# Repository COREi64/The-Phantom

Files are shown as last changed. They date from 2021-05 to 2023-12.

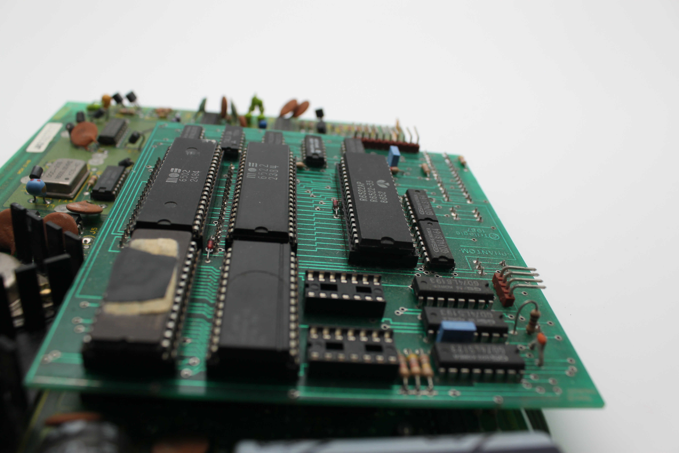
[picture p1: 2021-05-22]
Photos/Pre-Deconstruction Photos/1671.2021_04_24.JPG

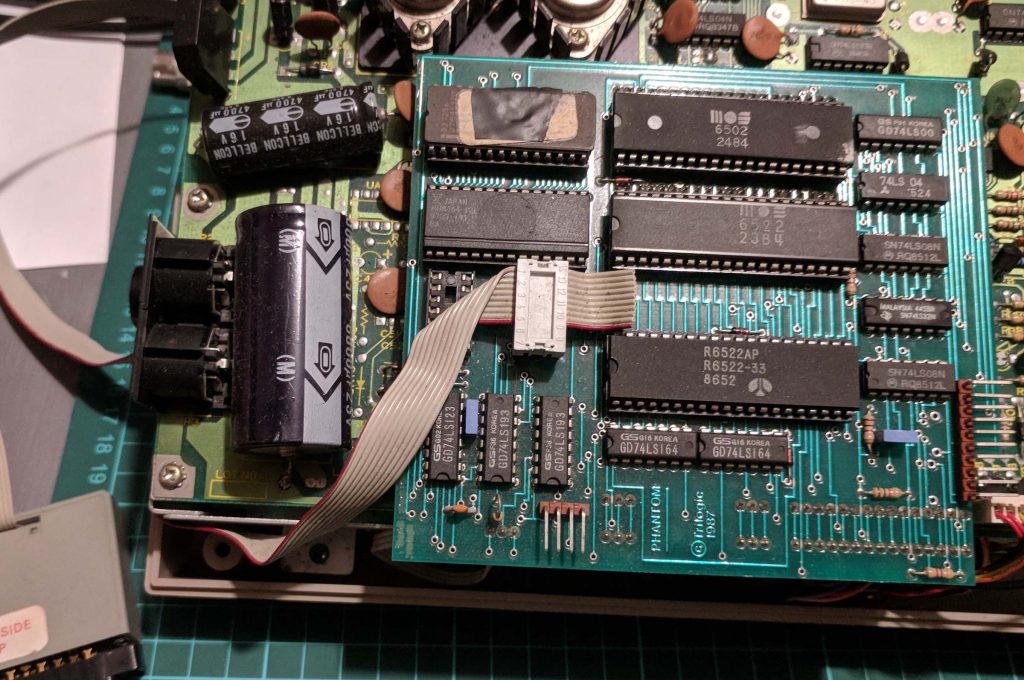
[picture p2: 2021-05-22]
Photos/Original Installation Photos/Phantom-Board-2-1024x680.jpg

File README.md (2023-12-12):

# The Phantom
Reproduction of the Phantom 1541 Drive Enhancement

Order your PCB's for this project directly from PCBWay, using the following links:

Back in about the 1986 timeframe, Tri-logic (UK) began marketing a board named "The Phantom".  I cannot speak to the commercial success of this product, today this board is one of the most rare Commodore "artifacts" known to still exist, especially in north america.  Being a product that resided within the host Commodore 64 and 1541 disk drive, it's reasonable to expect that as the years progressed knowledge that the product was installed in the system would have been forgotten.  Then, as the years march on, these machines are disposed of, given that those people have moved on with technology.

As a result, very few examples of this exist anymore.  For the most part, all that remained was a few short reviews, a magazine advertisement and miraculously a copy of the dedicated copier program that worked in concert with the board.  But up until recently the board has simply been gone.

A few years ago a good friend of mine (John Barrell) mentioned to me that he had found one of these installations in a Commodore job-lot that he had purchased local to him.  To understand who John was, is to think of a good natured man who shared a passion for Commodore products and was focused on the preservation of this hardware and software.  John however did not possess the skills to recreate the installation.  I offered to do this for him, as I had previously preserved other hardware such Chip Gracey's ISEPIC cartridge.  John and I came to an arrangement and he shipped the boards (drive board and kernal board) to me.  Unfortunately John passed away earlier this year, and never had the chance to see his wish come true.  Johns goal was the preservation of this hardware, and I am going to ensure that his wish is fulfilled.

This project has long since passed verification and testing, and has been found to be a fully functional, fully tested re-creation of the original Phantom drive accelerator.  This project in it's entirety is now available here in this github repository for anyone in the community to build and enjoy.  John wanted this product to the preserved for future entheusiasts.  This wish of his has now been realized.  Unfortunately we have not yet located the original documentation for the Phantom.  As such, all of the commands and features listed in the "user manual" is information that has been gleaned through testing, advertisements and disassembly.  Some of the features remain elusive.  I am hopeful that one day someone will locate an original Phantom manual and donate scans/photos of this document to this repository.

I will continue adding information as I work through this project and as more information becomes available.

If you fancy building this yourself, I've uploaded the board files to PCBWay's Shared Projects, so anyone can order their very own PCB's and build their own Phantom!  How exciting eh!  The Phantom is now within your reach.  Click on the links below to order the boards.

<a href="https://www.pcbway.com/project/shareproject/Tri_Logic_Phantom_Main_1541_Drive_Board_4dde7b70.html">PCB from PCBWay</a> <B>Click to order the Phantom Drive Board PCB</B>

<a href="https://www.pcbway.com/project/shareproject/Tri_Logic_Phantom_Kernal_Board_199d37ed.html">PCB from PCBWay</a><B>Click to order the Phantom Kernal Board PCB</B>

<a href="https://www.pcbway.com/project/shareproject/Tri_Logic_Phantom_Userport_Board_2852a004.html">PCB from PCBWay</a><B>Click to order the Phantom Userport Board PCB</B>

Phantom-AD-766x1024

NOTE: Effective March 5th, 2023, I have uploaded the design files as well as the gerbers of this project so that this wonderful product, that was almost lost to history, can be preserved and enjoyed well into the future.

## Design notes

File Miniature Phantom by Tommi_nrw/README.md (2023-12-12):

This is a variant of the original Phantom Reproduction found in this github that was supplied by John Barrel.

Based entirely on that work, this is an optimized reduced version of the original Trilogic Phantom.  The board is physically quite a bit smaller, and much easier to install as a result of this.
The design has been tested by the project creator and found to function correctly.  So for those looking to build a Phantom to experience what it was like, in a smaller easier to build package, this is certainly a version that could be considered.

Although there is no PCB at the moment for the parallel cable, I'm hoping that one will become available to make the deployment of this version easier, as it can be confusing as to how to wire the PCB without access to a convenient parallel cable PCB.

It should be noted that Thomas Linke has donated this project to this original Phantom Github repository for the Commodore community to enjoy for those that come after us.  The effort spent on creating this terrific board is greatly appreciated and is a wonderful addition to this continually expanding repository of all things Phantom related.

COREi64

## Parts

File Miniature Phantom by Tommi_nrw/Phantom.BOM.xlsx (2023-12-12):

IC1 | 6502 | 40 pin socket
IC2 | 6522 | 40 pin socket
IC3 | 6522 | 40 pin socket
IC4 | 6264 | 28 pin socket
IC5 | 28C256 | 28 pin socket
IC6 | 47LS123 | 16 pin socket
IC7 | 47LS08 | 14 pin socket
IC8 | 74LS193 | 16 pin socket
IC9 | 47LS00 | 14 pin socket
IC10 | 74LS164 | 14 pin socket
IC11 | 74LS04 | 14 pin socket
IC12 | 74LS32 | 14 pin socket
IC13 | 74LS164 | 14 pin socket
IC14 | 74LS08 | 14 pin socket
IC15 | 74LS193 | 16 pin socket
C1-15 | 100nF
C6A | 47pF
C6B | 100nF
CW | 100nF | (not needed)
R1 | 1k
R2 | 100k
R3-R6 | 4k7
JP1 | 2x7 pinheader | for parallelcable
PX | 1x5 pinheader | (not needed)
JP3 | 12x1 pinheader | on/off, Dev#...
P3 | 3x1 pinheader | connection to UC1
WP | 2x1 pinheader | for connecting writeprotection input/output

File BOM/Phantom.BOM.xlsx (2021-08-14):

Phantom Drive Board Bill of Materials
Part ID | Parts | Mouser Part number | QTY | Description |  | Source
 | 27256 |  | 1 | EPROM |  |  | Compatible SRAM
 | MB8464-12L |  | 1 | SRAM
 | 6502 |  | 1 | CPU/MOS |  | Obtained from 1541 Drive Board | Goldstar | 76C88
 | 6522 | 955-W65C22N6TPG-14 | 2 | Versatile Interface Adapter (VIA/MOS) |  | One obtained from 1541 Drive Board | Hitachi | 6264
 | 74LS123 | 595-SN74LS123N | 1 | dual retriggerable monostable multivibrator, clear |  |  | Hyundi | 6264
 | 74LS193 | 595-SN74LS193N | 2 | synchronous presettable up/down 4-bit binary counter, clear |  |  | Mitsubishi | 5165
 | 74LS164 | 595-SN74LS164N | 2 | 8-bit serial-in parallel-out (SIPO) shift register, asynchronous clear, not output latch |  |  | Mosel/Vitelic | 6264
 | 74LS00 | 595-SN74LS00N | 1 | quad 2-input NAND gate |  |  | NEC | 4464
 | 74LS04 | 595-SN74LS04N | 1 | hex inverter gate |  |  | OKI | 5165
 | 74LS08N | 595-SN74LS08N | 2 | quad 2-input AND gate |  |  | Samsung | 6264
 | 74LS32N | 595-SN74LS32N | 1 | quad 2-input OR gate |  |  | Sony | 5864B
 |  |  |  |  |  |  | Toshiba | 5564/5565
R1, R4, R5, R6, R8 | 1K | 660-MFS1/4CCT52R1001 | 5 | Resistor
R2, R7 | 4.7K | 660-MF1/4CCT52R4701F | 2 | Resistor
R3 | 100K | 660-MFS1/4DC1003F | 1 | Resistor
D1, D2, D3 | 1N4148 | 512-1N4148 | 3 | Fast switching diode
C2 | 47p ceramic | 810-FG28C0G1H470JNT0 | 1 | 47p Ceramic Capacitor
C1, C3 | Mkt-hq-370-ph | 80-RSBDC3100DQ00K | 2 | 100nf 10 63v Polyester Film Capacitor
 | 28p wide socket |  | 2 | double wipe
 | 40p wide socket |  | 5 | double wipe
 | 14p narrow socket |  | 9 | double wipe
 | 16p narrow socket |  | 3 | double wipe
 | 15p 2.54 female strip |  | 1 | straight
 | 3p 2.54 female strip |  | 2 | straight
 | 15p 2.54 male strip |  | 1 | straight
 | 3p 2.54 male strip |  | 3 | straight
 | ~~10p 2.54 male strip~~ |  | 0 | 90 degree | Not needed - these are test points used when the board was developed.
 | ~~4p 2.54 male strip~~ |  | 0 | 90 degree | Not needed - these are test points used when the board was developed.
 | 40p machine pin strip |  | 4 | straight
Phantom Kernal Board Bill of Materials
Part ID | Parts |  | QTY | Description |  | Source
 | 28p wide socket |  | 1 | double wipe
 | 24p machine pin strip, male/male |  | 2 | straight
 | 3p 2.54 male strip |  | 1 | 90 degree
 | 3p Dupont cable with 3p female |  | 1 | *for switch to toggle kernals
 | DPST switch |  | 1 | *for switch to toggle kernals
 | 2.2K |  | 2 | 0805 Resistor
 | 27256 |  | 1 | EPROM/EEPROM
 | PCB |  | 1 | Phantom Kernal PCB
Phantom Parallel Connector Board Bill of Materials
Part ID | Parts |  | QTY | Description |  | Source
 | 10 conductor ribbon cable |  | 4 ft
 | 7p machine pin strip, male/male |  | 4
 | Userport edge connector |  | 1
 | PCB |  | 1 | Phantom Parallel Connector PCB
 | 3D Designed Userport Connector Case |  | 1

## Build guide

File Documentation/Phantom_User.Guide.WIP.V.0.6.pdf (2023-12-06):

The PHANTOM

INSTRUCTIONS
Version 0.6

PLEASE READ THIS
BOOKLET BEFORE
USING THE PHANTOM

## The Phantom

### INTRODUCTION:

Thank-you for buying (or building your very own) the NEW! Phantom. The parallel disk turbo system every 1541 wants but nobody’s been able to get since 1987!

- Expert Compatible – Program the Expert in less than 2 seconds
- Speeds up ALL drive functions
- Full error checking retained – essential for
reliability. | Other | systems | sacrifice | this
crucial function to achieve speed increases but are in fact NO FASTER, only LESS RELIABLE.
- 8 function key commands for major functions.
- 60 additional commands including
- File lock and unlock
- Write protect ignore, no need to notch disks
- Set device number
- Screen on/off
- GO1541 – reverts to standard 1541
- Many | more | useful | commands | aid
compatibility | (disable | function | keys,
disable extra ram etc.)
- Drive | monitor | – | commands | include
disassemble, | fill, | compare, | hunt,
assemble, execute etc etc.
- Compatible with most commercial software.
- Reliable – does not corrupt disks unlike rival products.
- Switchable kernel replacement included for 64 or 128 (in 64 mode)
- British designed and manufactured, available exclusively from Trilogic
- Upgradable – DOS, Kernal & Copier upgrades will be available soon to give extra features for a nominal sum.

- The LOAD command can load files under the I/O area, so theoretically you can load 248 blocks (from the start of basic at $0801) or even 252 block files (starting from the tape buffer). This has never been seen in any other speeder ever created for the Commodore.

The Phantom consists of these components.

1. Phantom Drive Board
2. Phantom Drive Board Sync Cable
3. Phantom Kernal Replacement with Switch
4. Parallel Cable

Please read/reference the installation section of this manual for correct installation of your new Phantom. Trilogic cannot be held responsible for any damage caused due to incorrect installation.

### Compatibility:

The Trilogic Phantom board is compatible with all “long board” Commodore 1541 disk drives (110v & 220v
models). | These are the drives manufactured around
1987 or prior. | You can tell the drive is correct as
it will look like the following picture.

<<< INSERT PHOTO HERE >>>

In terms of Commodore 64 compatibility, so long as the computer has a socketed kernal ROM, it can be deemed compatible. If your computer doesn’t have a socketed kernal ROM, then you’re going to have to remove the ROM and replace it with a socket.

If this is beyond your capability, seek competent professional assistance.

### Keyboard Shortcuts:

The following are various keyboard shortcuts incorporated into the Phantom hardware to assist in making your computing experience more productive.

<CTRL-RESTORE>:

Resets the screen colors to the original factory default state of dark blue screen, light blue border and light blue text. Does not affect the contents of memory.

<RUNSTOP-RESTORE>:

Resets the screen colors to the PHANTOM default state of dark grey screen, light grey border and yellow text. Does not affect the contents of memory.

<RUNSTOP-( key)>:

Resets the computer as though you pressed a hardware reset button or issued an SYS64738 reset command.

<CommodoreKey-RUNSTOP>:

Loads the first file on your diskette into basic memory space. The command that’s issued is LOAD”0:*”,8

<SHIFT-RUNSTOP>:

Loads the first file on your diskette into the memory space where the program was originally saved from. The command that’s issued is LOAD”0:*”,8,1

Function Keys:

f1 - @8$:*
f2 - @9$:*

f3 - LOAD
f4 - SAVE"
f5 - RUN:
f6 - LIST
f7 - @
f8 - sys61916

### Built-In Functions:

Custom Directory Function: £

This feature allows you to create a customized directory of your diskette. To further explain I will illustrate with an example.

As we all know, it’s possible to have a LOT of different programs on a single side of a diskette given it’s large capacity of 170KB of storage space. And each of these programs can be made up of many different files. As such, it can be difficult to quickly determine what exactly is on the disk. Well, the Phantom to the rescue.

Let’s assume that you have the following programs on your disk.

1 Jumpman
2 Gyruss
3 Ms.Pacman
4 Ft. Apocalypse
5 Dig Dug
6 Drol
7 BCs Quest for Tires
So, that’s a lot of files. | To make a custom
directory, you’ve just seen the first step. | Enter
your list of programs that you’d find on your disk as shown above. It looks like a little program with line numbers right? Good.

Now with your diskette in the drive, and the write protect open, type the following:

SAVE “£”,8 (assuming your drive is 8)

That’s it.

Now to use the custom directory, type the following:

$£

Instead of displaying the actual directory, it will show you that list you just created. And the beauty of it is that you can put anything in that list you want to make it as meaningful as you’d like!

Interactive Editor Function:

Very little at this point is known about this function. I will highlight what is currently known, and update as more information becomes available.

@U0S<FILENAME>

This command opens the “FILENAME” for write output, and creates that file as a PRG file on the floppy disk. When this command is issued, the drive starts spinning, and the FILENAME <prg extension> is created on the diskette and opened for writing.

@U0L<FILENAME>

This command is presumably to load the above noted “FILENAME” and display it on the screen.

*** more testing and investigation is required for this command.

### Commands:

@ : Command Character:

This is the character that prefixes all DOS commands. It is interchangeable with the > command.

> : Command Character:

This is the character that prefixes all DOS commands. It is interchangeable with the @ command.

@& : Utility Loader:

The utility loader is the command which will load a USR file from disk into disk drive memory where it will then execute. The filename must be of a USR type, and the filename must be prefixed with the & character.

It should further be noted that when using this command, the <filename> you enter in the syntax below must have the & omitted.

Syntax/variants:

@&<filename>

The syntax assumes you have a file on floppy disk of a USR format, prefixed with the & character.

@£ : <<< unknown >>>:

This command generates 62, file not found, 00, 00 error.

Syntax/variants:

Have yet to determine the syntax for this.

@= : System Status:

This command displays a list of current option status’ as well as the drive rom identification. This may also do a soft reset on the drive at the same time (unconfirmed)

Syntax/variants:

Displays the following information.

73,8K PHANTOM DOS V1.1E,08,08
90, RAM ENABLED,00,00
91,TURBO ENABLED,00,00
92,SCREEN BLANKING ENABLED,00,00 98,BUMPS ENABLED,00,00
99,WRITE PROTECT ENABLED,00,00

@$ : Directory:

This command will display the contents of the directory on the diskette. The <Commodore-key> will pause the directory listing, and the RUNSTOP key will stop the directory listing. These are ideally suited for when you’re looking at a very long directory or you want to stop part way through when you’ve found what you’ve been looking for.

Syntax/variants:

@$ (directory of drive 0 of current device) @$$ (shows directory header & blocks free only) @0:$ (directory of drive 0 of current device) @0:$pa (only shows files starting with “pa”)

@1 : Enable TAPE Support:

I’m listing this separately to bring it to your attention that this is how you enable TAPE support. Normally, when powered up, TAPE support is not available, as the default commands are focused directly to the disk drive. By issuing this command you are redirecting focus to the TAPE drive. All subsequent I/O commands that would normally be directed to the drive now go to TAPE.

Syntax:

@1

Functional Example:

Once the command is issued, LOAD or SAVE will access the plugged in datasette recorder.

@n : Directing DOS commands to a specific Drive number:

In order to “focus” your machine on a specific drive number, you can issue the @<number> command. This will direct focus of all future DOS commands for your computing session or until you change it to a specific drive number.

Syntax:

@<drive number>

Functional Example:

@8 – Will direct all DOS commands to drive 8 @9 – Will direct all DOS commands to drive 9 @10 – Will direct all DOS commands to drive 10

@An : Soft Re-Numbering your Drive:

The disk drive, by default from the factory, is device #8. Unless you’ve physically changed this on the 1541 logic board, your drive will have that drive number assigned to it when you power it on. Soft renumbering allows you to change the device number of your drive without any physical changes.

Syntax:

@A <device-number>

Functional Example:

In order to use this command, DOS must have focus
on your current active drive. | By default, we
will assume that your drive is device 8. | To
ensure DOS focus on drive 8, you can issue the @8 command. After that you can change the device to another number.

@A9 will then soft renumber your 1541 to device 9.

To change it back, or to issue any DOS commands on the newly renumbered drive, you need to first issue an @9 to direct your DOS focus to that drive.

Then, you can issue any DOS command and it will be directed by your computer to device 9.

To change it back, or to any other device number, simply issue the @A8 command to change your drives number back to device 8. Don’t forget to re-focus DOS to device 8 now using the @8 command.

@BH : Seek Drive Head to Track Zero:

The purpose of this is to force the drive to find track 0 on your floppy drive. There are times when your floppy drive head may become “lost”, that could prevent you from loading a directory or any software for that matter. Issuing an @BH will correct that problem.

Syntax:

@BH

Functional Example:

@BH <return>

From the basic prompt, type @BH and press return. The drive will spin, and you will hear a slight banging in your drive. This is a normal sound. Once the drive stops spinning, the process is complete.

@BQ : <<<unknown>>>:

The purpose of this command is unknown.

Syntax / Functional Example:

This command issued as @BQ will generate a machine response of:

10, no track 1 sensor, 00, 00

@CD : <<<unknown>>>:

The purpose of this command is unknown.

Syntax / Functional Example:

This command issued as @BQ will generate a machine response of:

26, write protect on, 18, 01

@EA : Enable ALL:

The purpose of this command is to enable all of the listed system functions. Regardless of what their current state is, this command will enable them all and display their status on the screen.

Syntax :

@EA

Functional Example:

Enables all functions and returns a response on the screen as the example shows:

@EA <return>

90,RAM ENABLED, 00, 00
91,TURBO ENABLED, 00, 00
92,SCREEN BLANKING ENABLED, 00, 00 93,PHANTOM COMMANDS ENABLED, 00, 00 94,FAST SAVER ENABLED, 00, 00 95,FAST FORMAT ENABLED, 00, 00
96,PARALLEL BUS ENABLED, 00, 00
98,BUMPS ENABLED, 00, 00

It should also be noted that the @EA command can be stacked with other single commands that follow: Examples are as follows:

@EBC <return> will enable Bumps and Phantom Commands the following

98,BUMPS ENABLED, 00, 00
93,PHANTOM COMMANDS ENABLED, 00, 00

@ENP <return> will enable Fast Save and Parallel Bus with the following

94,FAST SAVER ENABLED, 00, 00
96,PARALLEL BUS ENABLED, 00, 00

EB : Enable Bumps:

The purpose of this command is to activate the “Bumps Enabled” to the current state.

Syntax :

@EB

Functional Example:

Returns a response on the screen as the example shows:

@EB <return>

98,BUMPS ENABLED, 00, 00

@EC : Enable Phantom Commands:

The purpose of this command is to set the “Phantom Commands” as enabled to be the current state.

Syntax :

@EC

Functional Example:

Returns a response on the screen as the example shows:

@EC <return>

93,PHANTOM COMMANDS ENABLED, 00, 00

@EF : Enable Fast Saver:

The purpose of this command is to set the “Fast Saver” as enabled to be the current state.

Syntax :

@EF

Functional Example:

Returns a response on the screen as the example shows:

@EF <return>

94,FAST SAVER ENABLED, 00, 00

@EN : Enable Fast Format:

The purpose of this command is to set the “Fast Format” as enabled to be the current state.

Syntax :

@EN

Functional Example:

Returns a response on the screen as the example shows:

@EN <return>

95,FAST FORMAT ENABLED, 00, 00

@EP : Enable Parallel Bus:

The purpose of this command is to set the “Parallel Bus” as enabled to be the current state.

Syntax :

@EP

Functional Example:

Returns a response on the screen as the example shows:

@EP <return>

96,PARALLEL BUS ENABLED, 00, 00

@ER : Enable RAM:

The purpose of this command is to set the “RAM” as enabled to be the current state.

Syntax :

@ER

Functional Example:

Returns a response on the screen as the example shows:

@ER <return>

90,RAM ENABLED, 00, 00

@ES : Enable Screen Blanking:

The purpose of this command is to set the “Screen Blanking” as enabled to be the current state.

Syntax :

@ES

Functional Example:

Returns a response on the screen as the example shows:

@ES <return>

92,SCREEN BLANKING ENABLED, 00, 00

@ET : Enable Turbo:

The purpose of this command is to set the “Turbo” as enabled to be the current state.

Syntax :

@ET
@+
@-

Functional Example:

Returns a response on the screen as the example shows:

@ET <return>

91,TURBO ENABLED, 00, 00

To toggle Turbo mode, perform the following commands

@+ enables Turbo mode
@- disables Turbo mode

@FL : File Lock:

The purpose of this command is to lock one or
more files on diskette. | This prevents deletion
(scratching) of the file. | The only way to wipe
out a locked file is to unlock it first, or format the diskette.

File locking can be done to a single file, multiple specified files up to a maximum of 5 at once, or with a wildcard (*). Using a wildcard will allow you to do all of the files on a diskette.

When doing a list of up to five filenames, you cannot allow them to wrap to the next line, as this command does not support wrapping.

Syntax :

@FL:<file1>,<file2>,<file3>,<file4>,<file5> @FL:<filename>
@FL:*
@FL:F* (lock all files starting with F)

@FU : File UnLock:

The purpose of this command is to unlock one or more files on diskette. This allows deletion (scratching) of the file to be done if the user wishes to do so.

File unlocking can be done to a single file, multiple specified files up to a maximum of 5 at once, or with a wildcard (*). Using a wildcard will allow you to do all of the files on a diskette.

When doing a list of up to five filenames, you cannot allow them to wrap to the next line, as this command does not support wrapping.

Syntax :

@FU:<file1>,<file2>,<file3>,<file4>,<file5> @FU:<filename>
@FU:*
@FU:F* (unlock all files starting with F)

@GO1541 : Revert to Stock ROM:

The purpose of this command is to allow the user to revert the drive back to the original factory Commodore 1541 Drive ROM.

Syntax :

GO1541

Functional Example:

Returns a response on the screen as the example shows:

@GO1541 <return>

73,CBM DOS V2.6 1541,00,00

@H : Header:

The purpose of this command is to rename the header (diskette name) of the diskette. This is the name that is used when formatting a diskette, and the name that appears reversed when listing a directory.

This is a non-destructive process with respect to the data on the diskette. You may perform this function without risk of loss of data.

Syntax :

@H0:<header name>

Functional Example:

@H0:Trilogic Phantom

Take note that the header name you choose must be at least 1 character long and no longer than 16 characters.

@I : Initialize:

The purpose of this command is to initialize the diskette.

Syntax :

@I0:

@KA : Disable ALL:

The purpose of this command is to disable all of the listed system functions. Regardless of what their current state is, this command will disable them all and display their status on the screen.

Syntax :

@KA

Functional Example:

Enables all functions and returns a response on the screen as the example shows:

@KA <return>

90,RAM DISABLED, 00, 00
91,TURBO DISABLED, 00, 00
92,SCREEN BLANKING DISABLED, 00, 00 93,PHANTOM COMMANDS DISABLED, 00, 00 94,FAST SAVER DISABLED, 00, 00 95,FAST FORMAT DISABLED, 00, 00
96,PARALLEL BUS DISABLED, 00, 00
98,BUMPS DISABLED, 00, 00

It should also be noted that the @KA command can be stacked with other single commands that follow: Examples are as follows:

@KBC <return> will disable Bumps and Phantom Commands the following

98,BUMPS DISABLED, 00, 00
93,PHANTOM COMMANDS DISABLED, 00, 00

@KNP <return> will disable Fast Save and Parallel Bus with the following

94,FAST SAVER DISABLED, 00, 00
96,PARALLEL BUS DISABLED, 00, 00

@KB : Disable Bumps:

The purpose of this command is to de-activate the “Bumps Enabled” to the current state.

Syntax :

@KB

Functional Example:

Returns a response on the screen as the example shows:

@KB <return>

98,BUMPS DISABLED, 00, 00

@KC : Disable Phantom Commands:

The purpose of this command is to set the “Phantom Commands” as disabled to be the current state.

Syntax :

@KC

Functional Example:

Returns a response on the screen as the example shows:

@KC <return>

93,PHANTOM COMMANDS DISABLED, 00, 00

@KF : Disable Fast Saver:

The purpose of this command is to set the “Fast Saver” as disabled to be the current state.

Syntax :

@KF

Functional Example:

Returns a response on the screen as the example shows:

@KF <return>

94,FAST SAVER DISABLED, 00, 00

@KN : Disable Fast Format:

The purpose of this command is to set the “Fast Format” as enabled to be the current state.

Syntax :

@KN

Functional Example:

Returns a response on the screen as the example shows:

@NN <return>

95,FAST FORMAT DISABLED, 00, 00

@KP : Disable Parallel Bus:

The purpose of this command is to set the “Parallel Bus” as disabled to be the current state.

Syntax :

@KP

Functional Example:

Returns a response on the screen as the example shows:

@KP <return>

96,PARALLEL BUS DISABLED, 00, 00

@KR : Disable RAM:

The purpose of this command is to set the “RAM” as disabled to be the current state.

Syntax :

@KR

Functional Example:

Returns a response on the screen as the example shows:

@KR <return>

90,RAM DISABLED, 00, 00

@KS : Disable Screen Blanking:

The purpose of this command is to set the “Screen Blanking” as disabled to be the current state.

Syntax :

@KS

Functional Example:

Returns a response on the screen as the example shows:

@KS <return>

92,SCREEN BLANKING DISABLED, 00, 00

@KT : Disable Turbo:

The purpose of this command is to set the “Turbo” as disabled to be the current state.

Syntax :

@KT
@+
@-

Functional Example:

Returns a response on the screen as the example shows:

@KT <return>

91,TURBO DISABLED, 00, 00

To toggle Turbo mode, perform the following commands

@+ enables Turbo mode
@- disables Turbo mode

@ME : <<< unknown >>>:

The purpose of this command is unknown.

Syntax :

@ME:

Functional Example:

Returns a response on the screen as the example shows:

@ME <return>

The command accesses the 1541, then reports 62,FILE NOT FOUND,00,00

@ML : <<< unknown >>>:

The purpose of this command is unknown.

Syntax :

@ML:

Functional Example:

Returns a response on the screen as the example shows:

@ML <return>

Reports “Memory Located and Protected”

@MN : <<< unknown >>>:

The purpose of this command is unknown.

Syntax :

@MN:

Functional Example:

Returns a response on the screen as the example shows:

@MN <return>

Reports “Memory Protection Enabled”

@MP : <<< unknown >>>:

The purpose of this command is unknown.

Syntax :

@MP:

Functional Example:

Returns a response on the screen as the example shows:

@MP <return>

Reports “Memory Protection Enabled”

@MU : <<< unknown >>>:

The purpose of this command is unknown.

Syntax :

@MU:

Functional Example:

Returns a response on the screen as the example shows:

@MU <return>

Reports “Memory Protection Disabled”

@N : Format Diskette:

The purpose of this command is to format/prepare a diskette such that files can be stored on the magnetic medium.

This command has an enhanced feature that allows you to format a diskette to 40 tracks. Typical capacity on a stock 1541 is formatting to 35 tracks.

35 tracks equates to 664 blocks free
40 tracks equates to 749 blocks free

This higher capacity works fine on standard DSDD diskettes. This additional storage space is only accessible when the computer is in full Phantom mode.

The header name may only be 1 to 16 characters in length. The ID may only be 2 characters in length.

To enable the enhanced format, add a + after the ID value when formatting.

Syntax :

@N0:<header name>,<id>{+}

Functional Example:

Formatting a standard 35 track/664 block free diskette.

@N0:TRILOGIC PHANTOM,35 <return>

Formatting a standard 40 track/749 block free diskette.

@N0:TRILOGIC PHANTOM,40+ <return>

@P0-9, PA-N : <<< unknown >>>:

The purpose of this command is unknown.

Syntax :

@P0-9, @PA-N:

Functional Example:

Returns a response on the screen as the example shows:

@P0-9, @PA-N <return>

Reports 70,NO CHANNEL,00,00

@PO : <<< unknown >>>:

The purpose of this command is unknown.

Syntax :

@po:

Functional Example:

Returns a response on the screen as the example shows:

@PO <return>

Reports 64,FILE TYPE MISMATCH,00,00

@Q : Kill DOS / Disable Function Keys:

The overall purpose of this command is unknown. What is known is that the pre-programmed function key assignments go away, and the built in DOS functions also disappear. No further testing has been done on this function at this time.

Syntax :

@Q:

Functional Example:

Returns a response on the screen as the example shows:

@Q <return>

Reports DOS KILLED

@R : Display Drive Registers:

The overall purpose of this command is unknown. What is known is that this command displays the 1541 drives registers it is believed.

Syntax :

@R:

Functional Example:

Returns a response on the screen as the example shows:

@R <return>

RST PC RA RX RY SP NV.BDIZC
>; C05C 10 00 FF 41 11111110

@RI : Display Drive Registers:

The overall purpose of this command is unknown. What is known is that this command displays the 1541 drives I/O registers it is believed.

Syntax :

@RI:

Functional Example:

Returns a response on the screen as the example shows:

@R <return>

>#1800 C1 FF 1A 00 C6 01 DF 01
>#1808 D9 AD FF 00 0B 40 82 FF >#1C00 D2 11 6F 00 58 16 00 3A
>#1C08 2F 1B 01 41 EC 02 C0 22

@S : Scratch/Delete files from Diskette:

The purpose of this command is to delete individual or groups of files from a diskette that’s inserted in your 1541 drive. Take note that if the files have been locked, then this
command will not delete them. | Instead, it will
report an error. | Also, if the diskette is write
protected, the files also cannot be deleted.

Syntax :

@S0:<filename>

Functional Example:

@S0:PACMAN | deletes file named PACMAN
@S0:P* | deletes all files starting with P

@U9 : Disk Drive Reset:

The purpose of this command is to reset your disk drive to a powered on state, with the Phantom drive rom active.

Syntax :

@U9:

Functional Example:

Returns a response on the screen as the example shows:

@U9 <return>

Reports 73,8K PHANTOM DOS V1.1E,08,08

@V : Validate Diskette:

The purpose of this command is to rebuild the BAM (block allocation map) on the floppy diskette. The BAM is located on track 18. This is the only way of removing a corrupted file from the directory. A corrupted file may have a file length of zero, and have an asterisk (*) beside it. Once the validation command has completed, the BAM will have been rebuilt, and the corrupt file(s) will have been removed. This is a permanent modification that occurs.

Syntax :

@V:I | Validate and ignore read errors
@V:L | Validate and learn read errors

@WC : Write Protect Ignore until disk change:

The purpose of this command is to tell the disk drive that it should not observe the write protect sensor on the drive, even if the write protect tab is in place. This command will remain in place only while the current diskette is in the drive. As soon as it is removed from the drive, the drive sensor will return to normal function.

Syntax :

@WC

@WI : Write Protect Ignore:

The purpose of this command is to tell the disk drive that it should not observe the write protect sensor on the drive, even if the write protect tab is in place. This command will remain in place until it is either switched off or the drive is powered down.

Syntax :

@WI

@WN : Write Protect Return to Normal:

The purpose of this command is to tell the disk drive to return to normal detection mode. Typically this command would be used if you wanted to reverse the @WI command.

Syntax :

@WN

@WU : <<< unknown >>>:

Not a lot is known about this function. What it appears to do is modify the diskette in some fashion such that it is no longer possible to write to the diskette. No reversal process has been found other than the destructive FORMAT (@N) command. Use with caution.

Syntax :

@WU

Functional Example:

Returns a response on the screen as the example shows:

26,WRITE PROTECT ON,18,00

SYS61916 : RENEWED:

Not a lot is known about this function. What it appears to do is some sort of “NEW” function, but not a lot is known about it.

### Appendix: INSTALLATION:

Installation of this board into your drive will take approximately 30 minutes. Make sure you have a well lit and tidy work area before starting.

Additionally, your Commodore 64 will need to have a socketed kernal. If your Commodore 64 Kernal ROM (the chip marked as 901227-03) is soldered onto your computers mainboard, then please seek a qualified professional to remove the chip and install a socket. Attempting this yourself can cause irreparable damage to your computer if you don’t know what you’re doing. Nobody including Trilogic cannot be held responsible for any damage to your Commodore 64.

Tools required are:
- Phillips head screw driver
- Small flat head screwdriver
- Anti-static grounding strap for yourself.
STEP 1 : Remove / Replace the Kernal ROM in your 64.

Estimated Install time: 10 minutes

In this step, you will be removing your Kernal ROM from your machine and replacing it with THE PHANTOM rom provided in your package. This Phantom kernal replacement rom actually contains TWO ROMS.

1. Original Commodore Kernal ROM
2. Custom PHANTOM ROM. The most current version of the PHANTOM ROM is v1.07
- Remove the screws from your Commodore 64 (the three screws along the bottom front edge of the machine, and lift up the top half of the computer (like you would the hood of your car).

- Locate the kernal rom location on your Commodore 64 and remove it, taking note of the notch location on the chip.
- Insert the Phantom kernal rom adapter board into the same location, taking care to ensure the notch on the Phantom rom is oriented in the same fashion.
- Locate and install the provided switch in the case, or use the provided jumper if you prefer
to | always use the | Phantom kernal on your
machine.
- If you choose the jumper option, then unplug the switch and discard, and place the jumper across the two pins closest to the notch end of the chip on the Phantom kernal board.
- Close up your Commodore 64, and do a power on test of your Commodore 64. One of the switch positions will provide you with the factory start up screen, and the other position will be the Phantom start up screen that will look like figure 1.

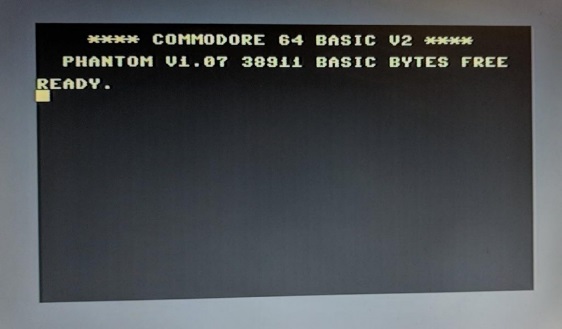
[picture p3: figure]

Figure 1

Step 2: Install The Phantom Drive Board

Estimated Install time: 30 minutes

In this step, you will be installing the brains and brawn of The Phantom. It may seem daunting, but take your time and make sure you have good lighting in your work area to ensure everything is plugged in as it should when you’re done.

Taking photos of the process as you go along before and after you remove/install components will help you should you forget how things were before and after during the installation process.

1. Open up the 1541 drive by removing the four screws on the underside of the drive. This requires that you use a Philips head screwdriver.
2. Once the top has been removed from the drive, if there is a metal shield installed above the main logic board, remove that as well. You won’t be able to use that shield if it is place after the Phantom is installed, as the Phantom occupies that space.
3. Remove the 6502 CPU at location UC4, and the 6522 VIA at location UC3 On the 1541 main board.
4. Remove the cables from locations P4, P5, P6 on the edge of the board taking note of their orientation. It helps to mark these connectors appropriately with a felt marker before removing them so you don’t forget how they were installed.
5. Connect the “sync” cable to the three pins on UC1 and UC2. Ensure you connect them to the correct pins as marked on the cable.

MOS325572-01 (UC1) : 1 – Pin19, 2 – Pin21 MOS6522 (UC2) : 3 – Pin 17
6. The next part is a little tricky, so make sure you really take your time lining up all the pins. Bending the pins on the underside of the Phantom board would be catastrophic, as that is not easily repaired.

It is for this reason it is HIGHLY RECOMMENDED that you install the two 40 pin sockets onto the male pin headers on the underside of the board BEFORE installing the board. In this way, if you happen to bend a pin installing the Phantom in your 1541, it will only be on the socket, not the male pin header on the Phantom. The socket is easier to replace than the pin headers on the board. If you purchased an assembled board, that is how it was delivered to you.

It helps to set it in place, then before pressing it in, use a flashlight to look between the boards and visually inspect where all the pins are... that they are all positioned where they should be. If you do that, you shouldn't have any problems.

If you're finding you're having troubles with it working, gently lift and lower the edge of the phantom where it plugs into the pins on the edge of the board. I've found that on some drives, those pins are somewhat corroded and you have to work them a bit to make all the connections.

7. Once the board is successfully pressed into the socket and pin locations on the board, insert the cables you removed from the logic board in step 4 and sync cable you installed in step 5 to their respective points on the Phantom.
8. Insert the parallel cable connector onto the Phantom board (if you have not already done so), and route the ribbon cable out the back of the drive.
9. Before closing up the drive, connect the parallel cable to the Commodore 64 user port

(taking note of which side is up), connect your serial cable from the Commodore 64 to the 1541 drive containing your newly installed Phantom board, and power on the system.
10. You should be greeted with the Phantom start screen when you power on your Commodore 64.
11. Press the ‘@’ symbol and press return. The computer should respond with the startup DOS response from the drive as follows:

73,8K PHANTOM DOS V1.1E,00,00

If you received this message then the board is successfully installed, and you may close up your 1541 drive.

If you do not, and/or the computer locks up when you do that, then you have not properly installed the board in the drive. More than likely, you probably have not pressed the board down sufficiently onto the 1541 logic board, or you have bend a pin or pins.

At this point, you should remove the Phantom logic board, and examine all of the pins. If you bent some, very carefully and slowly try to straighten them. In most cases, unless the pins have been severely kinked, you can straighten the pins once if you’re careful before they break off. If you break off any pins, the board will need to be repaired and the connector strip will need to be replaced.

Assuming that you’ve gotten the correct DOS response, congratulations!

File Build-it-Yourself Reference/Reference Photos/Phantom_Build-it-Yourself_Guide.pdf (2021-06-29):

The PHANTOM

Build-it-Yourself
GUIDE
Version 0.1

PLEASE READ THIS
BOOKLET BEFORE
CONSTRUCTING YOUR PHANTOM

### The Phantom Build-it-Yourself Guide

### INTRODUCTION:

You’re either curious as to how you’d go about building a Phantom yourself, or you have a pile of parts in front of you that are destined to become your very own Phantom board. Either way, you need to follow a certain assembly procedure otherwise you’ll
run | into | some | assembly problems | throughout | the
process.

The assembly of the Phantom board requires good lighting and a reasonable block of un-interupted time to successfully complete.

You should also be warned, that there are a number of vias in very close proximity to one another, and as such, if you’re not careful you could bridge while soldering. Pay close attention while soldering.

So warm up your soldering station and let’s get going.

### Parts and Tools:

If you don’t already have the parts to build this, you can either buy just the PCB from COREi64.com and source the parts yourself, or purchase a complete parts set with PCBs.

If you’re getting the parts yourself, use the BOM on the Phantom GitHub as your shopping list of what you need to buy.

There are a number of components that when assembled result in the Phantom system. These components are:

- Phantom Drive Board
- Sync clip for the main Phantom drive board
- Kernal board with switch
- Parallel/userport cable and board

Each of these will be assembled separately, and these components can be assembled in any order.

Full resolution photos taken during the creation of each of these items can be found on the Phantom Github.

### Phantom Drive Board:

This is the main board that will reside on top of the 1541 logic board.

Step 1:

Install resistors and diodes

Step 2:

This is crucial that you get this right. All of these machine pins and pin headers need to be perfectly aligned with the 1541’s logic board. In the absence of an assembly jig that you likely won’t have access to, you should be using your

1541 logic board as the jig. Install the machine pins in the 6502 and 6522 sockets after having first removed those chips from positions UC4 and UC3

Then, install machine pins, P4 P5 and P6 male and female connectors and pin headers.

Once you have all of these connection points soldered onto your drive board, install the sync clip pin header.

WARNING :

Now that you have the machine pins soldered onto your drive board, be VERY CAREFUL not to bend those pins. For these pins to be the correct size to be able to plug into a socket, they have to be as thin as they are, which makes them extremely fragile. IF you were to break off a pin, it is exceedingly difficult to repair a board like that. This kind of damage CAN be repaired, but requires some advanced de-soldering skills as to not damage the PCB in the process.

These pins will be unprotected until you complete the next step. After the next step is completed, you’ll be able to put the 40 pin machine sockets over the machine pins you just soldered on, and they will be then well protected.

Step 3:

Install the three 40 pin dual wipe sockets, two 28 pin dual wipe sockets and two 14 pin sockets onto the top of the board and solder them in place. Be careful soldering between the machine pins on the underside, ensuring that you don’t melt or bend any pins. Also be careful you don’t bridge any sold points with adjacent vias.

Step 4:

Install the two 40 pin machine sockets over the two 40 pin machine pins on the underside of the
board. | Take your time and be careful not to bend
any of these pins. | They are very fragile and can
easily be bent or broken. Once you’ve installed these sockets, they will remain in place. These will eventually plug into the 6502 and 6522 sockets when you finally install the Phantom. You should never remove these sockets from the machine pins, as they not only space the board off the 1541 logic board, but also protect these fragile connection points.
Step 5:

Solder all of the remaining IC’s onto the Phantom. The Phantom drive board has indications silk screened onto the board as to which chip goes where, as well as the chip orientation. Follow these directions on the board explicitly.

Step 6:

Install the 47pf capacitor, and the two 100nf polyester capacitors on the board. These are the last two components that you should be installing on the Phantom drive board.

Step 7:

Plug the second VIA on the board, as well as the drive rom and SRAM chip. These are marked on the PCB, and you can also review the build photos on the Github for reference.

Step 8:

Success. Provided you haven’t bridged any vias or missed any components/solder connections, you will now have a complete Phantom drive board in front of you. Congratulations.

### Sync Clip:

This is a three wire cable that connects from the Phantom drive board to three locations on the 1541 logic board.

There is really only one step here. Connect the IC clips to the end of the three wire harness, and if your wire doesn’t have a connector on the end, solder one on. Might be good to mark which wire is which based on the installation instructions. Note that Pins 1, 2 and 3 are marked on the underside of the PCB which indicate the orientation of the connector.

Be careful ensuring that you make the correct connections to the board, otherwise your Phantom will not work, and you could potentially damage the board and/or drive.

### Kernal Board with Switch:

This is the kernal replacement board that will be installed inside the C64 you plan on using with your Phantom equipped 1541.

Step 1:

If the surface mounted 2.2K resistors are not pre-soldered for you on the PCBs, then solder those components on first.

Step 2:

Solder the two 12 pin machine pin strips to the under side of the board (opposite side to where the resistors are soldered on).

Step 3:

Solder the 28 pin dual wipe socket to the top of the board.

Step 4:

Solder the 3 pin 90 degree male header onto the board beside where the resistors are. They should be mounted from the top side of the board.

Step 5:

Solder the three wire cable to the DPDT switch. If no connector is on the other end of the cable, solder a female dupont connector to that. This will mate to the 3 pin header you soldered on in
Step 3.
Step 6:

The kernal board is now complete. Follow the installation instructions to replace your factory kernal in the 64 with this new switched Phantom kernal.

### Parallel/Userport Cable and Board:

This is the parallel data cable that connects between the Phantom logic board and the userport of your Phantom equipped Commodore 64 computer.

Step 1:

With your 10 wire ribbon cable in hand, separate a couple inches on each end, strip and tin the conductor.

Step 2:

Install the machine pin headers to the underside of the parallel connection board. Refer to the photos on the Github.

Step 3:

Feed the ribbon cable through the slots of the parallel cable and solder them in according to the color sequence found in the photos on the Github.

Step 4:

Solder the ribbon cable to the user port connector, again referencing the photos provided on the Phantom github.

Take not that the side that has the single black wire represents the top of the connector.

Step 5:

Install the connector and cable into the custom designed user port connector housing. Ensure you have the orientation correct in the housing. The single black wire connected to the user port connector should be on top. Please refer to the github photos to ensure your orientation is correct. The small cylindrical piece is the cable block that will help reduce strain on the solder points if the cable is pulled.

Once the top and bottom of the housing has been mated, tighten the two M3 screws from the underside of the housing.

Do not over tighten the M2 screws that attach the userport connector to the housing, as this will pull the heatset through the user port connector. Just make it snug, that’s all it needs.

Step 6:

The parallel cable construction is complete, and you’ve reached the end of the construction of your Phantom system. Now all that’s left is that you carefully install it into your 1541 drive.

I will caution you that you should take your time installing this onto your 1541. There are a LOT of connection points between the Phantom drive board and the 1541. If any one isn’t quite right, your Phantom drive system will not work. If after you’ve carefully installed it, you find it’s not working, you may need to press down or lift and lower the edge of the board over the Px pins to establish a positive connection. These pins on your 1541 may have corroded over the years, so patience should be observed in
installing this. | ESPECIALLY in the 6502 and 6522
connection points. | A broken or offset pin will
render the Phantom installation non-functional.

### Appendix: INSTALLATION:

Installation of this board into your drive will take approximately 30 minutes. Make sure you have a well lit and tidy work area before starting.

Additionally, your Commodore 64 will need to have a socketed kernal. If your Commodore 64 Kernal ROM (the chip marked as 901227-03) is soldered onto your computers mainboard, then please seek a qualified professional to remove the chip and install a socket. Attempting this yourself can cause irreparable damage to your computer if you don’t know what you’re doing. Nobody including Trilogic cannot be held responsible for any damage to your Commodore 64.

Tools required are:
- Phillips head screw driver
- Small flat head screwdriver
- Anti-static grounding strap for yourself.
STEP 1 : Remove / Replace the Kernal ROM in your 64.

Estimated Install time: 10 minutes

In this step, you will be removing your Kernal ROM from your machine and replacing it with THE PHANTOM rom provided in your package. This Phantom kernal replacement rom actually contains TWO ROMS.

1. Original Commodore Kernal ROM
2. Custom PHANTOM ROM. The most current version of the PHANTOM ROM is v1.07
- Remove the screws from your Commodore 64 (the three screws along the bottom front edge of the machine, and lift up the top half of the computer (like you would the hood of your car).
- Locate the kernal rom location on your Commodore 64 and remove it, taking note of the notch location on the chip.
- Insert the Phantom kernal rom adapter board into the same location, taking care to ensure the notch on the Phantom rom is oriented in the same fashion.
- Locate and install the provided switch in the case, or use the provided jumper if you prefer
to | always use the | Phantom kernal on your
machine.
- If you choose the jumper option, then unplug the switch and discard, and place the jumper across the two pins closest to the notch end of the chip on the Phantom kernal board.
- Close up your Commodore 64, and do a power on test of your Commodore 64. One of the switch positions will provide you with the factory start up screen, and the other position will be the Phantom start up screen that will look like figure 1.


Figure 1

Step 2: Install The Phantom Drive Board

Estimated Install time: 30 minutes

In this step, you will be installing the brains and brawn of The Phantom. It may seem daunting, but take your time and make sure you have good lighting in your work area to ensure everything is plugged in as it should when you’re done.

Taking photos of the process as you go along before and after you remove/install components will help you should you forget how things were before and after during the installation process.

1. Open up the 1541 drive by removing the four screws on the underside of the drive. This requires that you use a Philips head screwdriver.
2. Once the top has been removed from the drive, if there is a metal shield installed above the main logic board, remove that as well. You won’t be able to use that shield if it is place after the Phantom is installed, as the Phantom occupies that space.
3. Remove the 6502 CPU at location UC4, and the 6522 VIA at location UC3 On the 1541 main board.

4. Remove the cables from locations P4, P5, P6 on the edge of the board taking note of their orientation. It helps to mark these connectors appropriately with a felt marker before removing them so you don’t forget how they were installed.
5. Connect the “sync” cable to the three pins on UC1 and UC2. Ensure you connect them to the correct pins as marked on the cable.

MOS325572-01 (UC1) : 1 – Pin19, 2 – Pin21 MOS6522 (UC2) : 3 – Pin 17
6. The next part is a little tricky, so make sure you really take your time lining up all the pins. Bending the pins on the underside of the Phantom board would be catastrophic, as that is not easily repaired.

It is for this reason it is HIGHLY RECOMMENDED that you install the two 40 pin sockets onto the male pin headers on the underside of the board BEFORE installing the board. In this way, if you happen to bend a pin installing the Phantom in your 1541, it will only be on the socket, not the male pin header on the Phantom. The socket is easier to replace than the pin headers on the board.

7. Once the board is successfully pressed into the socket and pin locations on the board, insert the cables you removed from the logic board in step 4 and sync cable you installed in step 5 to their respective points on the Phantom.
8. Insert the parallel cable connector onto the Phantom board (if you have not already done so), and route the ribbon cable out the back of the drive.

9. Before closing up the drive, connect the parallel cable to the Commodore 64 user port (taking note of which side is up), connect your serial cable from the Commodore 64 to the 1541 drive containing your newly installed Phantom board, and power on the system.
10. You should be greeted with the Phantom start screen when you power on your Commodore 64.
11. Press the ‘@’ symbol and press return. The computer should respond with the startup DOS response from the drive as follows:

73,8K PHANTOM DOS V1.1E,00,00

If you received this message then the board is successfully installed, and you may close up your 1541 drive.

If you do not, and/or the computer locks up when you do that, then you have not properly installed the board in the drive. More than likely, you probably have not pressed the board down sufficiently onto the 1541 logic board, or you have bend a pin or pins.

At this point, you should remove the Phantom logic board, and examine all of the pins. If you bent some, very carefully and slowly try to straighten them. In most cases, unless the pins have been severely kinked, you can straighten the pins once if you’re careful before they break off. If you break off any pins, the board will need to be repaired and the connector strip will need to be replaced.

Assuming that you’ve gotten the correct DOS response, congratulations!

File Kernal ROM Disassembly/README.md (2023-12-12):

Contained in this folder you will find the complete Phantom Kernal ROM Disassembly

This disassembly work was done entirely by Thomas Salzlechner, November 2023 and donated to the Phantom Github repository so that this wonderful device can be better understood by those that come in the future.

Many thanks are sent out to Thomas for his wonderfully detailed work and contribution to this project.

COREi64

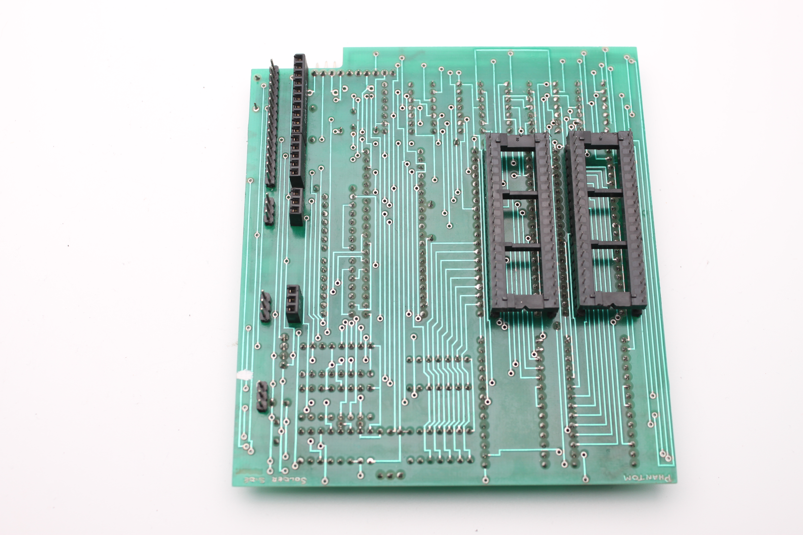
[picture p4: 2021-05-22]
Photos/Pre-Deconstruction Photos/1708.2021_04_24.JPG

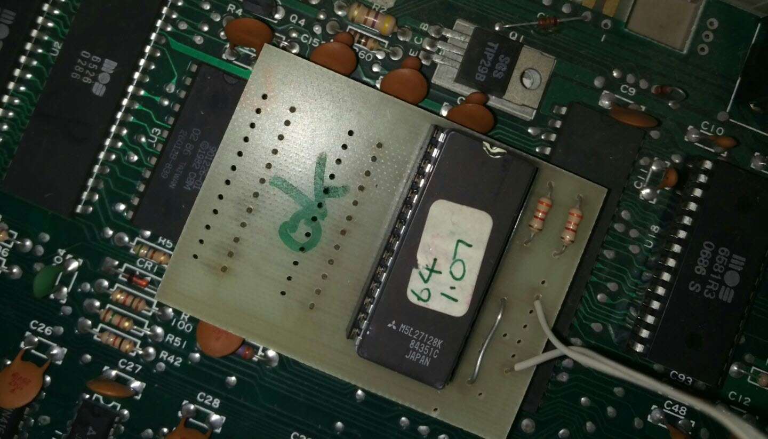
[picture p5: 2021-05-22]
Photos/Original Installation Photos/Trilogic Phantom Kernal Board C64.jpg

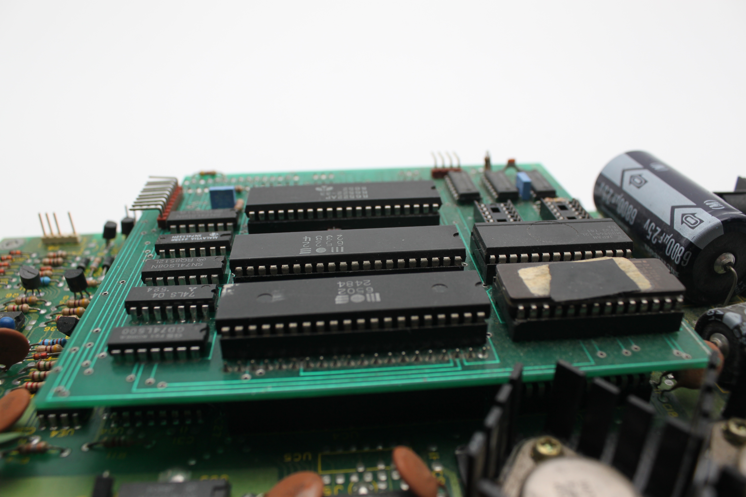
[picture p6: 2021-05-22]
Photos/Pre-Deconstruction Photos/1668.2021_04_24.JPG

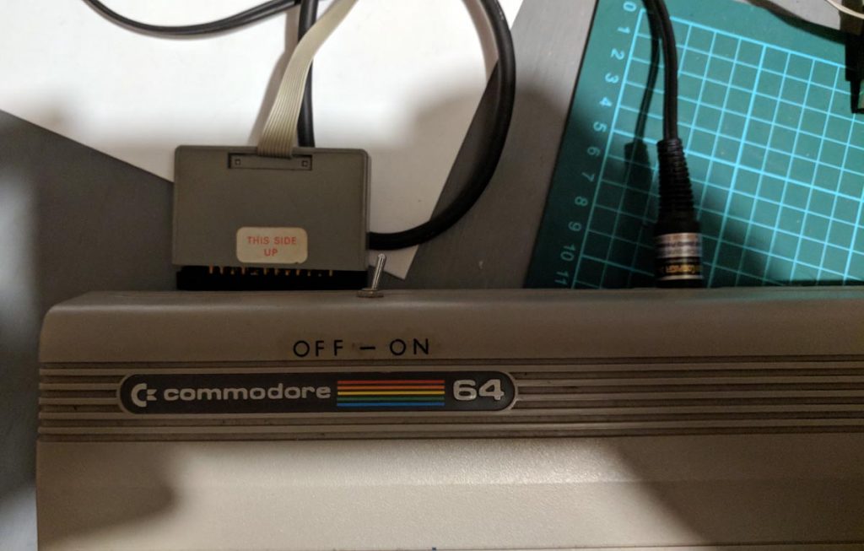
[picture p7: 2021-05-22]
Photos/Original Installation Photos/Phantom-connected-1024x653.jpg

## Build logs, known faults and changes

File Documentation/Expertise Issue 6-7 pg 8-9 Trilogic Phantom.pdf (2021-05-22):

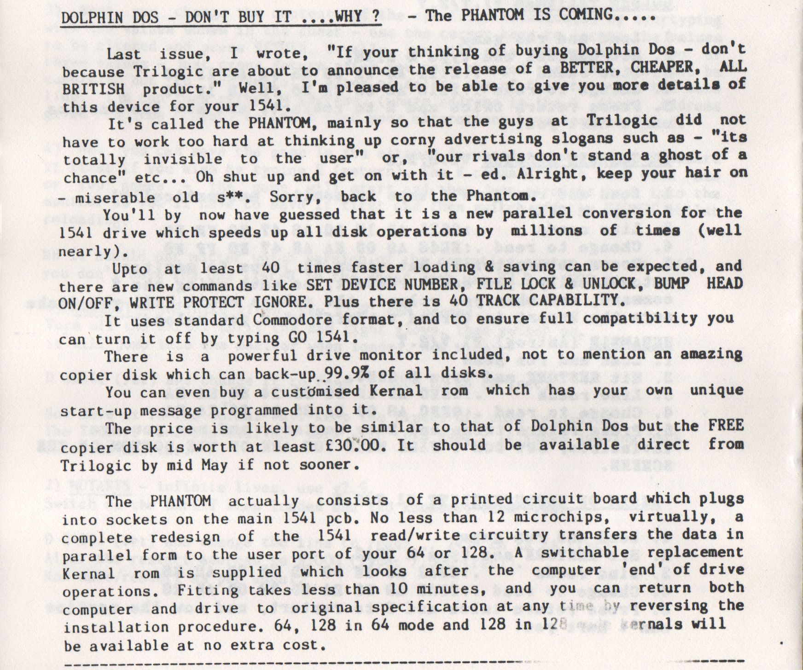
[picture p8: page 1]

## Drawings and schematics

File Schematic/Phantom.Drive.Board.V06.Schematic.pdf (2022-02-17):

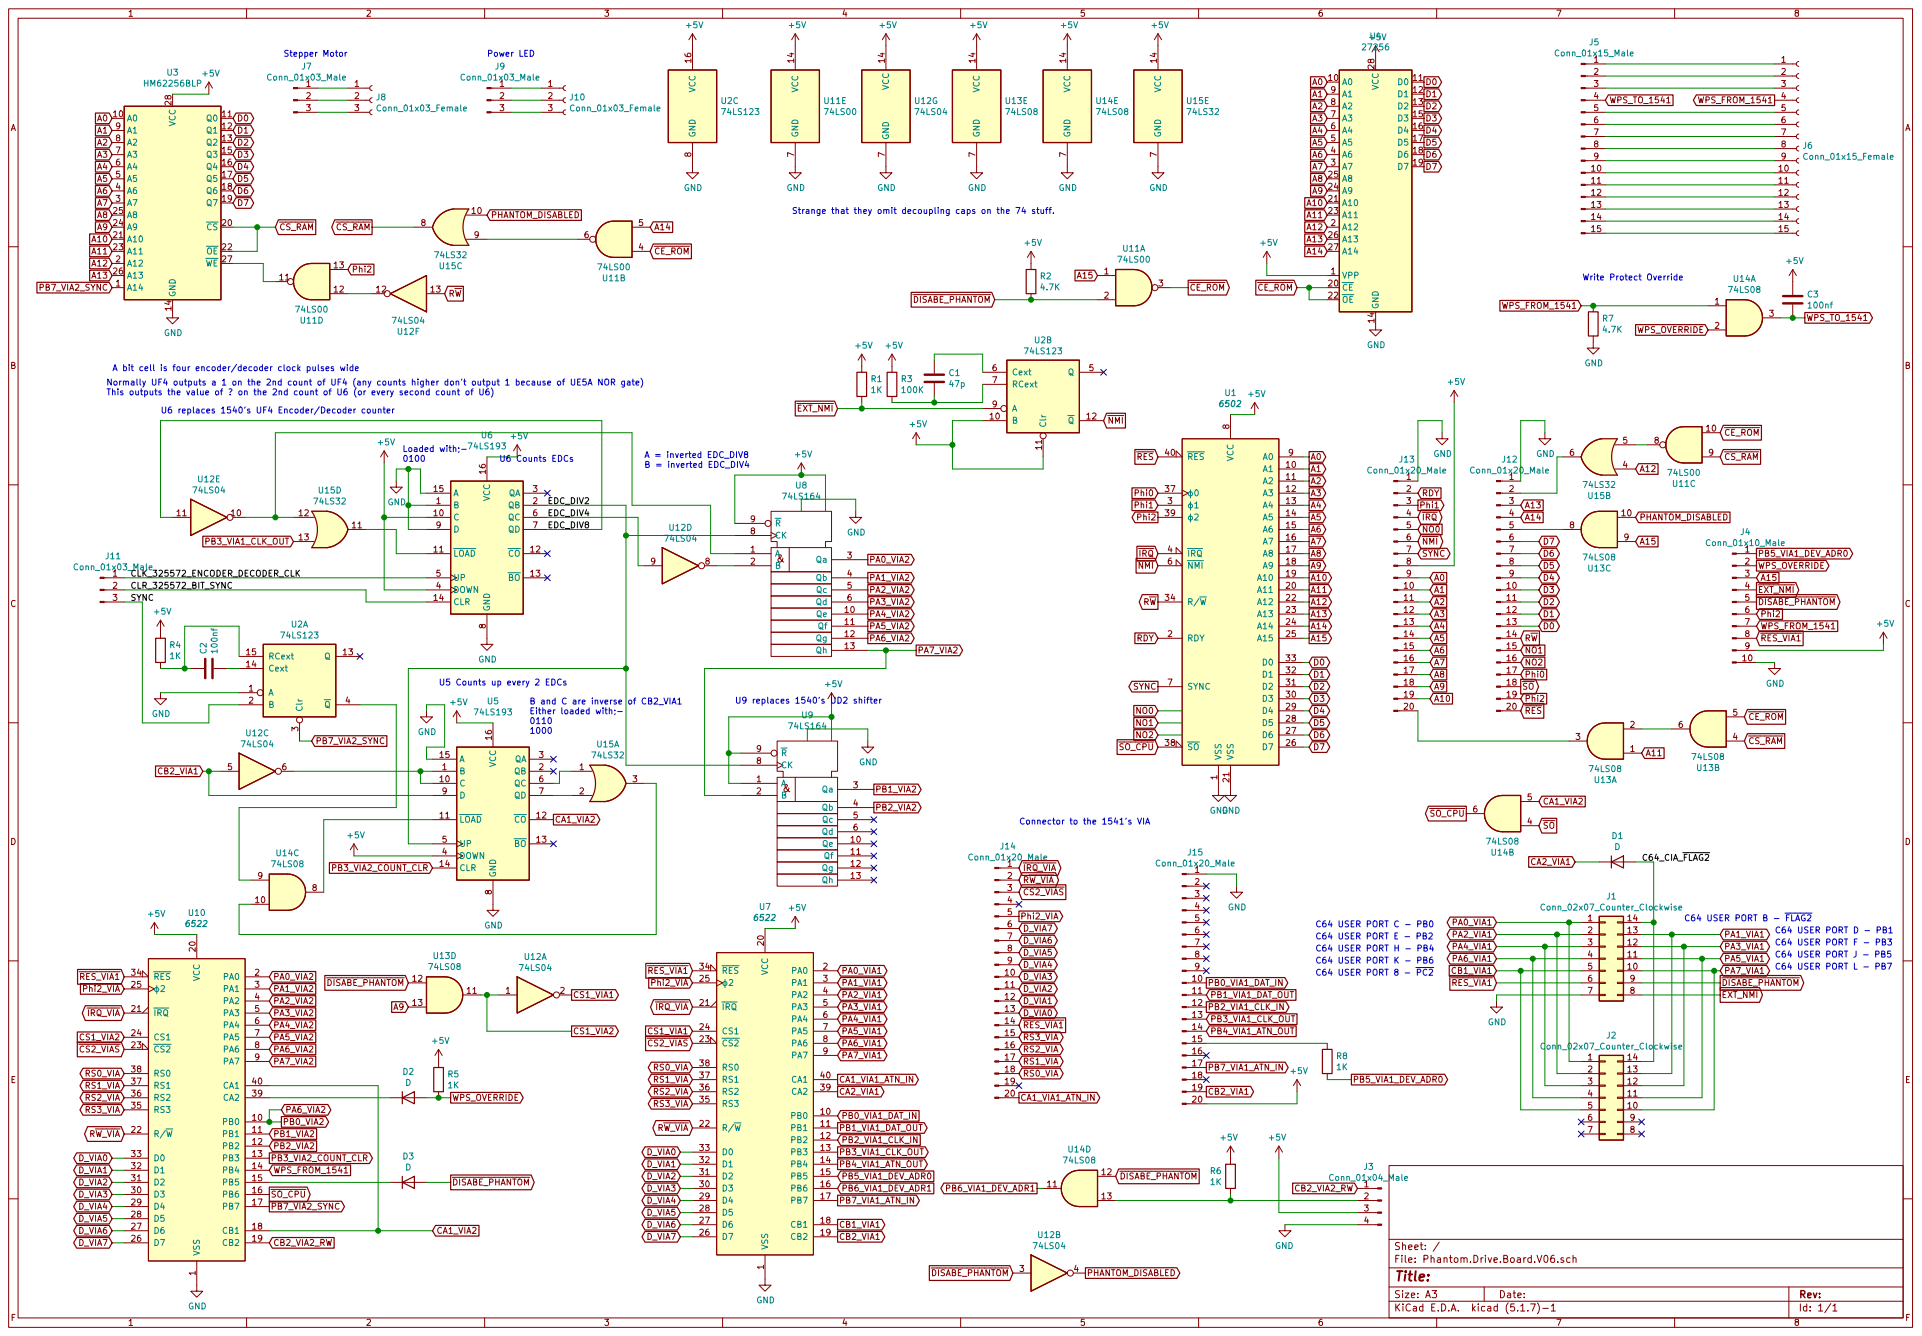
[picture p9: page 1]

A = inverted EDC_DIV8 B = inverted EDC_DIV4 A bit cell is four encoder/decoder clock pulses wide
Normally UF4 outputs a 1 on the 2nd count of UF4 (any counts higher don't output 1 because of UE5A NOR gate)

EDC_DIV8 EDC_DIV4 EDC_DIV2 B and C are inverse of CB2_VIA1 Either loaded with;- 0110

U5 Counts up every 2 EDCs

2 | | 13 12 11 10

6 | J2 Conn_02x07_Counter_Clockwise

Id: 1/1 Title: File: Phantom.Drive.Board.V06.sch Sheet: /

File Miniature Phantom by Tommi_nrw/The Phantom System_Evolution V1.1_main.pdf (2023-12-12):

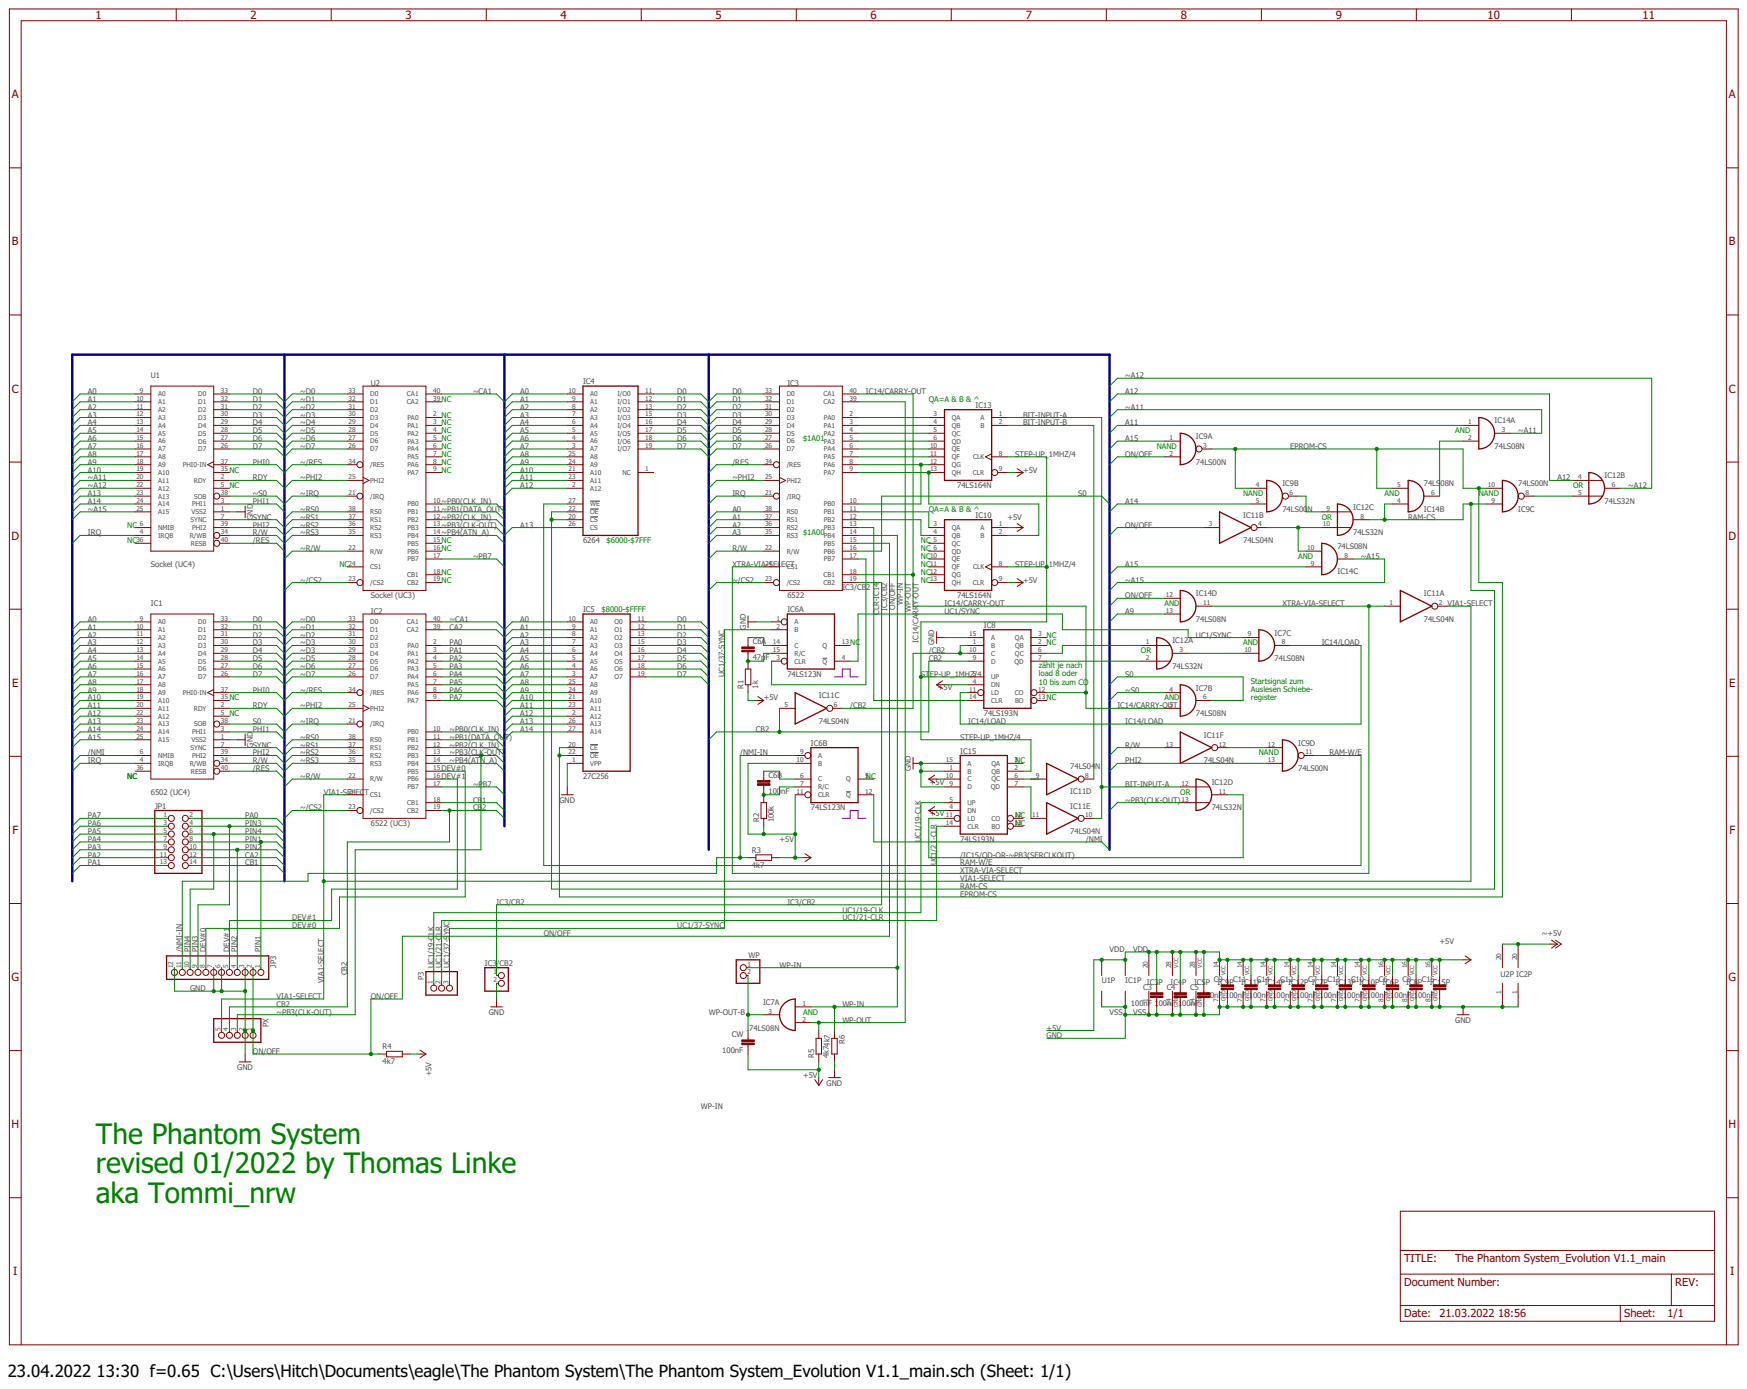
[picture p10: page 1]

XTRA-VIA-SELECT
VIA1-SELECT

IC3/CB2 | | | RAM-CS

EPROM-CS

ON/OFF

REV: TITLE: Document Number: The Phantom System_Evolution V1.1_main The Phantom System
revised 01/2022 by Thomas Linke
aka Tommi_nrw

23.04.2022 13:30 f=0.65 C:\Users\Hitch\Documents\eagle\The Phantom System\The Phantom System_Evolution V1.1_main.sch (Sheet: 1/1)

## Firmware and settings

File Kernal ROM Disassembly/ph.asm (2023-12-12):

; *******************************
; Trilogic Phantom Kernal 1.07
; Overlay for original CBM-Kernal
;
; disassembled and analyzed by
;
; Thomas Salzlechner, 11/2023
;
; ********************************
;

; **** assemble to $2000, origin is $e000

eprom		= $2000
offset		= eprom-$e000

; labels zeropage
linnum		= $14			; temp vars for calculations
index1		= $22			; used by LNKPRG
txttab		= $2b			; start BASIC code
vartab		= $2d			; start BASIC variables	
arytab		= $2f			; start BASIC arrays	
aryend		= $31			; end BASIC array	
fretop		= $33			; start BASIC strings	
memtop		= $37			; highest RAM address	
facho		= $62			; FAC#1	
facmoh		= $63			; FAC#1	
chrget		= $0073			; CHRGET, get next character
chrgot		= $0079			; CHRGOT, get last character
status		= $90			; ST status variable
stkey		= $91			; Flag for STOP and RVS
verck		= $93			; flag 0=load, 1=verify
bsour		= $95			; byte for IEC output
msgflg		= $9d			; 0=direct  $80=program
pcntr 		= $a3			; EOI flag
firt		= $a4			; temporary variable (tape, serial) 
count		= $a5			; temporary variable (tape, serial)
sal		= $ac			; address load lo
sah		= $ad			; address load hi
eal		= $ae			; end address lo
eah		= $af			; end address hi
phblank		= $b4			; $d011 value if screen blanking on
fnlen		= $b7			; length of filename
secadr		= $b9			; secondary address
device		= $ba			; primary device
fnadr		= $bb			; adress of filename lo
mych		= $bf			; serial buffer
stal		= $c1			; start address lo
stah		= $c2			; start address hi
tmp2		= $c3			; temp variable
ndx		= $c6			; # of chars in keyboard buffer
pnt		= $d1			; address of cursor pos lo
pntr		= $d3			; cursor positio in line
qtsw		= $d4			; quote mode
ldtb1		= $d9			; start addresses of screen lines

; labels page 2
keyd		= $0277			; keyboard buffer start
shflag		= $028d			; flag for shift/cbm
keylog		= $028f			; pointer to decoding table
autodn		= $0292			; flag screen scrollin 0=on
phdevice	= $029b			; phantom standard device, bit 7=1 fkeys off
enabl		= $02a1			; NMI enable flag used as temp var

; labels page 3
iload		= $0330			; vector into kernal LOAD routine

; labels BASIC
lnkprg		= $a533			; calc basic lines link adresses
stkrts1		= $a687			;
frmnum		= $ad8a			; evaluate numerical term
chkerr		= $ad99			; show type mismatch error
frmevl		= $ad9e			; evaluate term
frestr		= $b6a3			; check for string
linprt2		= $bdd1			; convert hex to dec, data already in FAC
plsv7		= $e200			; get byte to xr, check for comma
paoc16		= $e25d			; get filename, pointer already in INDEX1

; labels Kernal
csys1		= $e130			; part of SYS command
lp2		= $e5b4			; get char from keyboard buffer
loop3		= $e5cd			; keyboard input
xe617		= $e617			; call into CLP5, get first non space from the right
loop5		= $e632			; get char from screen to A
prt		= $e716			; print character on screen
scnrts		= $eb42			; part of RPT20, select keyboard column 7
ntalk		= $ed09			; IEC TALK
nlistn		= $ed0c			; IEC LISTEN
isour1		= $ed44			; call into ISOUR (ouput byte on IEC bus)
nsecnd		= $edb9			; secondary address after LISTEN
scatn		= $edbe			; pull ATN lo
ntksa		= $edc7			; secondary address after TALK
nciout		= $eddd			; output byte on IEC bus
nuntlk		= $edef			; IEC UNTALK
nunlsn		= $edfe			; IEC UNLISTEN
nacptr		= $ee13			; read byte from IEC bus
acp00a		= $ee1b			; call into NACPTR
clkhi		= $ee85			; pull CLOCK active (low)
clkhi2		= $ee88			; CLOCK low without reading port first
clklo		= $ee8e			; pull CLOCK inactive (high)
clklo2		= $ee91			; CLOCK HIGH without reading port first
datahi		= $ee97			; pull DATA active (low)
datahi2		= $ee9a			; DATA low withou readin port first
datalo		= $eea0			; pull DATA inactive (high)
wims		= $eeb3			; delay for 1 ms
ms1		= $f0bd			; table of OS messages
spmsg		= $f12b			; print message if in direct mode
msg		= $f12f			; print message
xf198		= $f198			; just an RTS
bn31		= $f1b1			; just for branching			
jx150		= $f2f1			; just for branching
ck20		= $f25f			; kust for branching (NOT OUTPUT FILE)
openi		= $f3d5			; open IEC and send filename
ld26		= $f4c4			; entry into LD25 (serial load) 
ld40		= $f4f3			; wait for IEC timeout
ld185		= $f5aa			; end of load, endadress in x/y
ld180		= $f5a9			; end address to X/Y and back ok
ld190		= $f5ae			; end of tape load routine, just for rts
luking		= $f5af			; SEARCHING FOR
sv26		= $f608			; callback into IEC save routine			
break		= $f633			; break error in IEC routine
clsei		= $f642			; close IEC file
clsei1		= $f646			; close IEC file
sv115		= $f68e
ud60		= $f6bc			; set flag for STOP and RVS
error4		= $f704			; file not found
error8		= $f710			; missing file name
error9		= $f713			; illegal device number
zzz		= $f7d0			; pointer to start of tape buffer
cste1		= $f817			; PRESS PLAY and wait for key			
rblk		= $f841			; read block from tape
tstop1		= $f8d6			; part of tape routines
rd80		= $faeb			; part of tape load routine
rd52		= $fb2f			; part of tape load routine
a0int		= $fd02			; check for exrom module
restor		= $fd15			; set standard vectors
udst		= $fe1c			; ora A to ST
prend 		= $febc			; IRQ end, pull registers
kstnam 		= $ffbd			; set filename parameters
kbsout		= $ffd2			; output character
kstop		= $ffe1			; check for STOP key
start		= $fffc			; reset vector

			; start at $e000
			*=$e000
			.offs offset

; load original kernal first (e.g. the VICE kernal file
; then assemble the overlays

			.binary "kernal"	


; hook into sys command, replace call to FRMNUM
; comes back with a call to FRMNUM if not hex

			*=$e12a
			.offs offset
				
csys			jsr hexsys 	; sys parameter

; hook into the save command, replaces call to PLSV
; to get parameters for save

			*=$e156
			.offs offset

csave 			jsr plsv1	; get filename parameters


; get parameters for load/save	

			*=$e1d4
			.offs offset

plsv 			ldy #$00	; load
			.byte $2c	; 
plsv1			ldy #$ff	; save
			jsr devchk	; check/correct device
			iny		; load: 1 save: 0 
			cmp #$01	; if device 1
			bne l1		; 
			dey		; load: 0 save: $ff
l1 			sty secadr	; secondary address
			sta device	; device address
			tya		; 
			beq l2		; if load
			iny		; y=0
			cpy shflag	; check for shift
			bne l3		; 
			dec secadr	; secadr -1
l3			lda #3		; for empty name use
			ldx #<runtb	; filename 0:* 
			ldy #>runtb	; 
l2			jsr kstnam	; set filename parameters
			jsr chrgot	; read last character
			jmp plsv2	; continue

; ***** changes to the sign-on  message

			*=$e49a
			.offs offset

			.null "  phantom v1.07 "


; **** print loading from $xxxx-, but stop printing if start address <$0800

			*=$e4b7
			.offs offset
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

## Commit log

2021-06-14 Bill of Materials
    [Phantom.BOM.xlsx]
2021-08-14 Update Phantom.BOM.xlsx
    Revised C1/C2 in BOM
    [Phantom.BOM.xlsx]
2022-02-17 Phantom schematic
2023-03-05 Gerbers & Eagle Files Added
    Added Gerber files and Eagle Design Files to the repository.
    [Phantom.Kernal.Board.V03.brd, Phantom.Parallel.Cable.Board.V2.brd, Phantom.V06.brd]
2023-12-12 Add Phantom v1.1 Variant
    Added miniature Phantom v1.1 Variant created by Tommi_nrw
    [Phantom.BOM.xlsx]
2024-01-20 Create Mini.Phantom.Parallel.Cable.Board.V01.gerbers.zip
    Userport PCB for Phantom Parallel cable connection for Mini-Phantom
